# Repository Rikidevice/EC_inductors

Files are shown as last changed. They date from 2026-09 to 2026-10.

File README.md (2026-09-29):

# PWR_MOD — контроллер индуктивного измерения проводимости солей с регулировкой pH
# PWR_MOD — Inductive Salt Conductivity Meter with pH Control

[Русский](#русская-версия) · [English](#english-version)

---

## Русская версия

Плата управления для системы индуктивного (бесконтактного) измерения
проводимости солей трендового типа с автоматической коррекцией pH.
Поддерживает два варианта управляющего модуля: **ESP32 / ESP32-S3-1.47**
и **STM32F407VET6**. Связь по **Modbus (RTU/ASCII)**.

### Возможности

- **Индуктивный метод измерения проводимости солей**
  - Приём сигнала с катушки детекции (Rx) через **полноценный АЦП**
    с **гальванической развязкой**.
  - Отдельный канал измерения **pH** (также через развязанный АЦП).
- **Температурный контроль**
  - **DS18B20** — температура жидкости (1-Wire).
  - **DHT22 (AM2302)** — температура и влажность воздуха в помещении.
- **Управляющие модули (на выбор / распайка под оба):**
  - `ESP32` (WROOM-32 и совместимые);
  - `ESP32-S3-1.47` (дисплейный модуль);
  - `STM32F407VET6`.
- **Два шаговых двигателя** для дозирования:
  - `pH Up` — драйвер A4988;
  - `pH Down` — драйвер A4988.
- **Modbus**
- **Питание и защита** — 12В от 1А

### Аппаратная часть

| Узел | Реализация | Примечание |
|---|---|---|
| MCU | ESP32 / ESP32-S3-1.47 / STM32F407VET6 | выбор при сборке |
| АЦП (Rx катушки) | MCP3551 | гальваническая развязка |
| АЦП (pH) | ADS1232 | гальваническая развязка |
| Датчик температуры жидкости | DS18B20 | 1-Wire |
| Датчик температуры/влажности воздуха | DHT22 (AM2302) | 1-Wire-подобный |
| Драйвер ШД №1 (pH Up) | A4988 | полноценная обвязка |
| Драйвер ШД №2 (pH Down) | A4988 | полноценная обвязка |
| Интерфейс связи | Modbus RTU / ASCII | RS-485 - SN65HVD72DR |

**Плата:** 4 слоя, 111,1-91,3 мм.

### Прошивка и протокол

- **Modbus:** [RTU / ASCII], адрес по умолчанию — `[1]`,
  скорость — `[9600 8N1 / 19200 8N1]`.
- **Карта регистров:** [ссылка на docs/modbus_registers.md или таблицу ниже].

#### Карта регистров (черновик)

| Адрес | R/W | Описание | Ед. |
|---|---|---|---|
| 0x0000 | R | Проводимость солей | мкСм/см |
| 0x0001 | R | pH | pH |
| 0x0002 | R | Температура жидкости (DS18B20) | °C |
| 0x0003 | R | Температура воздуха (DHT22) | °C |
| 0x0004 | R | Влажность воздуха (DHT22) | % |
| 0x0010 | W | Уставка pH | pH |
| 0x0011 | W | Команда насоса pH Up | — |
| 0x0012 | W | Команда насоса pH Down | — |
| 0x00FF | R/W | Служебный / версия ПО | — |

### Сборка и запуск

1. Подать питание 12В (есть защита от полярности).
2. Проверить индикацию [PWR, RUN].
3. Подключить сборку из катушек Tx [L2], Rx [L3].
4. Подключить pH-электрод к разъёму [J5].
5. Подключить DS18B20 к разъёму [18b20].
6. Подключить DHT22 к разъёму [DHT22].
7. Подключить RS-485 (A/B/GND) [J11]  к верхнему уровню.
8. Подать команду по Modbus и убедиться в отклике.

### Безопасность

- Измерительная и цифровая части разделены по земле и питанию.
- Шаговые двигатели питаются от входного напряжения 12В

### Лицензия

Проект распространяется под лицензией **MIT**. Полный текст — в файле [`LICENSE`](LICENSE).

### Автор

[Talgat / RikiDevice] — [rikimtfree@gmail.com]

---

## English version

Control board for an inductive (non-contact) salt conductivity measurement
system of trending type with automatic pH correction.
Supports two control module options: **ESP32 / ESP32-S3-1.47**
and **STM32F407VET6**. Communication over **Modbus (RTU/ASCII)**.

### Features

- **Inductive salt conductivity measurement**
  - Detection coil (Rx) signal acquisition via a **full-featured ADC**
    with **galvanic isolation**.
  - Dedicated **pH** measurement channel (also via isolated ADC).
- **Temperature monitoring**
  - **DS18B20** — liquid temperature (1-Wire).
  - **DHT22 (AM2302)** — ambient air temperature and humidity.
- **Control modules (selectable / footprint for both):**
  - `ESP32` (WROOM-32 and compatible);
  - `ESP32-S3-1.47` (display module);
  - `STM32F407VET6`.
- **Two stepper motors** for dosing:
  - `pH Up` — A4988 driver;
  - `pH Down` — A4988 driver.
- **Modbus** — communication with upper layer (PLC / SCADA / PC).
- **Power and protection** — [specify: input voltage, regulators,
  overcurrent protection, TVS, etc.].

### Hardware

| Block | Implementation | Notes |
|---|---|---|
| MCU | ESP32 / ESP32-S3-1.47 / STM32F407VET6 | selected at build time |
| ADC (Rx coil) | [part] | galvanically isolated |
| ADC (pH) | [part] | galvanically isolated |
| Liquid temperature sensor | DS18B20 | 1-Wire, [parasitic/external power] |
| Ambient temp/humidity sensor | DHT22 (AM2302) | 1-Wire-like, [4.7–10 kΩ pull-up] |
| Stepper driver #1 (pH Up) | A4988 | full support circuitry |
| Stepper driver #2 (pH Down) | A4988 | full support circuitry |
| Communication | Modbus RTU / ASCII | RS-485 [transceiver] |
| Power | [voltage] | [regulators / protections] |

**PCB:** 4 layers, [size, mm], [thickness, mm], [accuracy class].

### Repository layout
PWR_MOD/
├─ PWR_MOD.kicad_pro # KiCad project
├─ PWR_MOD.kicad_sch # schematic
├─ PWR_MOD.kicad_pcb # PCB layout
├─ gerbers/ # Gerber + drill files
├─ docs/ # datasheets, PDFs, notes
│ ├─ schematic.pdf
│ ├─ pcb_top.pdf
│ └─ pcb_bottom.pdf
├─ firmware/ # firmware sources (if any)
├─ .gitignore
└─ README.md
text

### Fabrication

1. Open the project in **KiCad [version]**.
2. Run ERC (schematic) and DRC (PCB) — report saved to `docs/`.
3. Generate Gerber + Excellon (drill) into `gerbers/`.
4. Send `gerbers/*.zip` to the PCB house.
   - Layers: 4 (Top, Inner1, Inner2, Bottom).
   - [Optional] controlled impedance if required for the detection coil.

### Firmware and protocol

- **Modbus:** [RTU / ASCII], default address — `[1]`,
  default baud — `[9600 8N1 / 19200 8N1]`.
- **Register map:** [link to docs/modbus_registers.md or table below].

#### Register map (draft)

| Address | R/W | Description | Unit |
|---|---|---|---|
| 0x0000 | R | Salt conductivity | µS/cm |
| 0x0001 | R | pH | pH |
| 0x0002 | R | Liquid temperature (DS18B20) | °C |
| 0x0003 | R | Ambient temperature (DHT22) | °C |
| 0x0004 | R | Ambient humidity (DHT22) | % |
| 0x0010 | W | pH setpoint | pH |
| 0x0011 | W | pH Up pump command | — |
| 0x0012 | W | pH Down pump command | — |
| 0x00FF | R/W | Service / firmware version | — |

### Assembly and startup

1. Apply power [voltage, polarity].
2. Check indicators [PWR, RUN, ERR].
3. Connect the Rx coil to connector [J?].
4. Connect the pH electrode to connector [J?].
5. Connect DS18B20 to connector [J?].
6. Connect DHT22 to connector [J?].
7. Connect RS-485 (A/B/GND) to the upper layer.
8. Send a Modbus command and verify the response.

### Safety

- Galvanic isolation of the ADC is mandatory: measurement and digital
  sections are separated by ground and power.
- Stepper motors are powered from a separate [voltage] rail and **must not**
  share ground with the isolated ADC.
- When handling pH reagents (Up/Down), observe [safety precautions].

### License

The project is distributed under the MIT license. The full text is in the [`LICENSE`](LICENSE).

### Author

[Talgat / RikiDevice] — [rikimtfree@gmail.com]

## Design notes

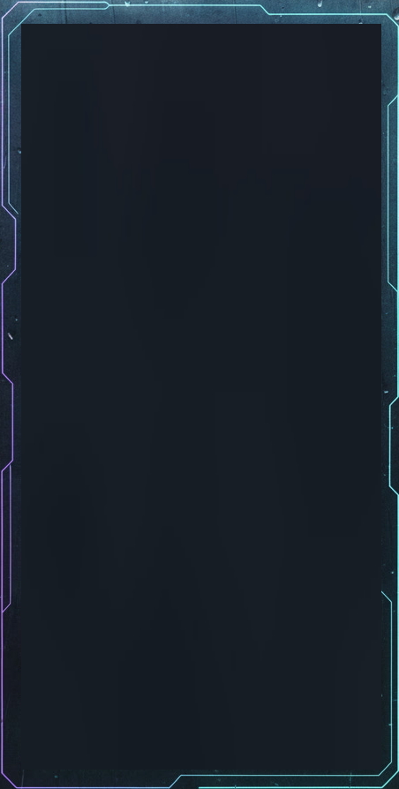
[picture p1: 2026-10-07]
UI/interface.jpg

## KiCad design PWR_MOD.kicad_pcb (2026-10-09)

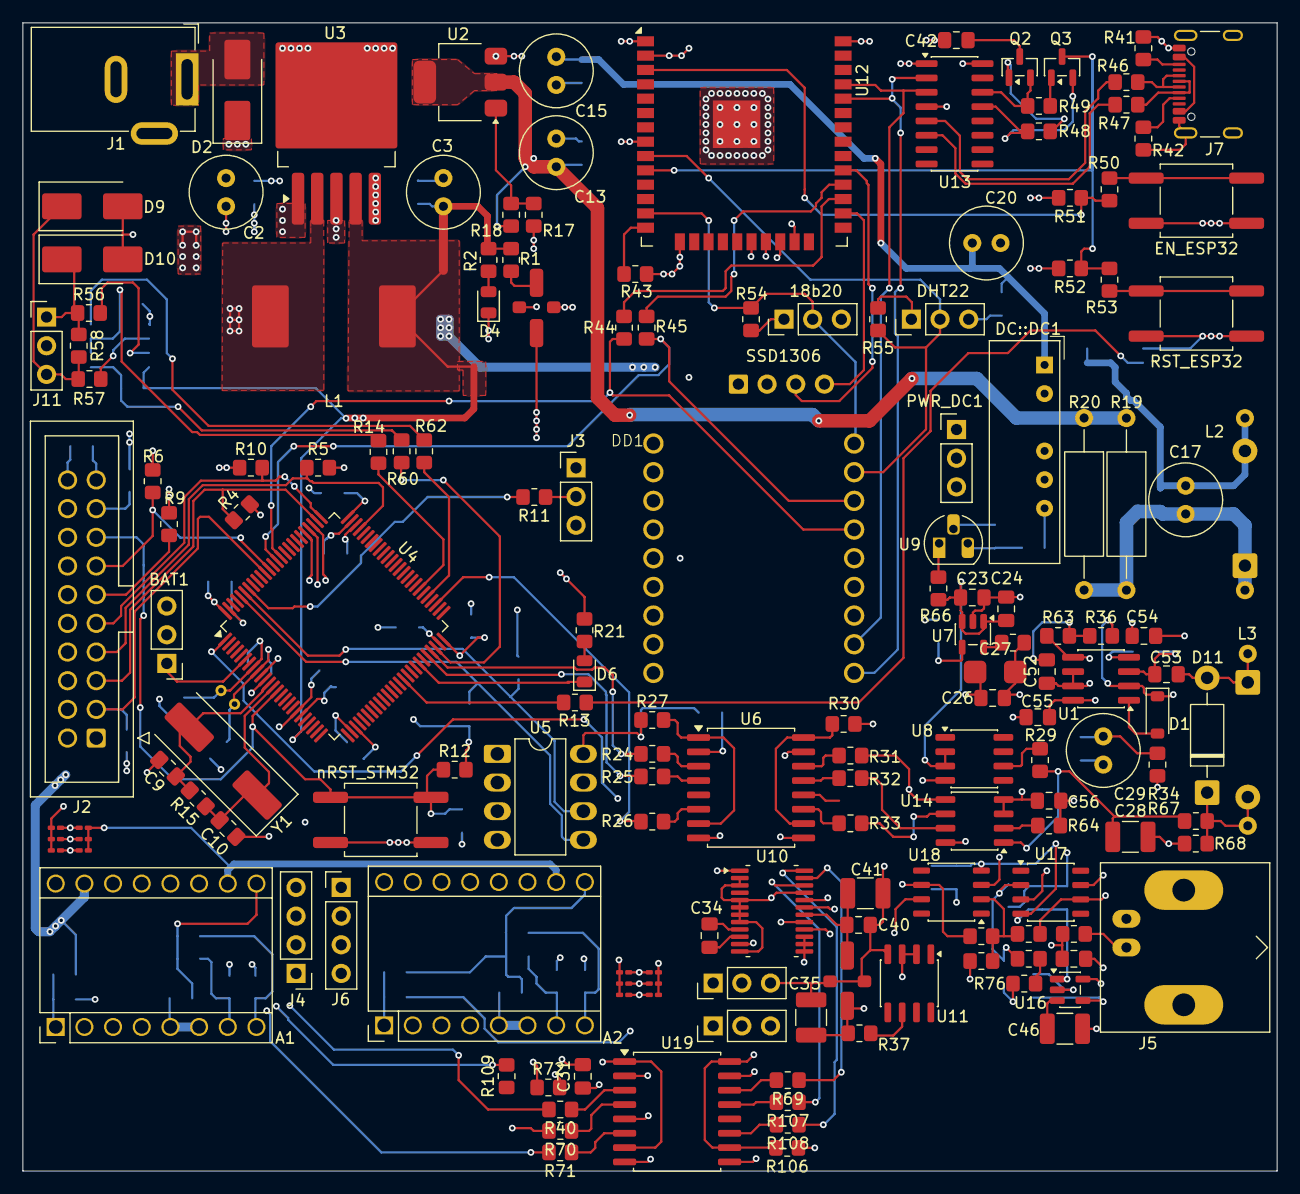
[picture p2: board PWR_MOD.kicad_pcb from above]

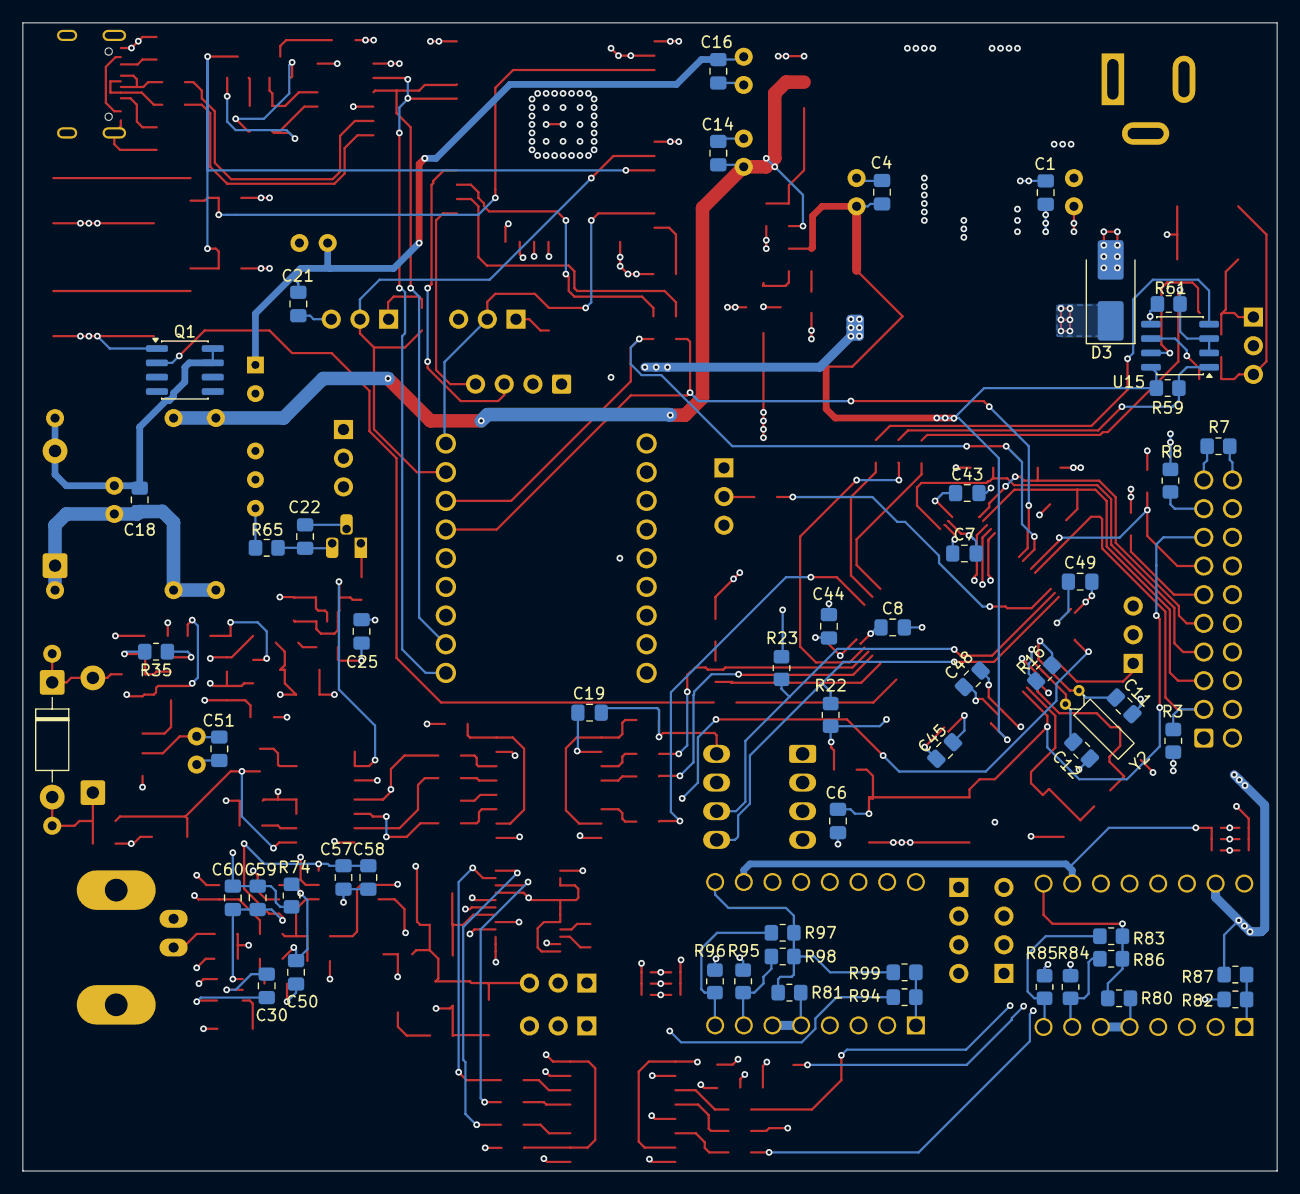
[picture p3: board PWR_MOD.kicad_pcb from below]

Board: 4 copper layers, 111.1 x 101.7 mm, 221 parts (57 on the bottom side), 164 nets.

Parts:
18b20: Conn_01x03; PinHeader_1x03_P2.54mm_Vertical
A1, A2: Pololu_Breakout_A4988; Pololu_Breakout-16_15.2x20.3mm
BAT1: Conn_01x03; PinHeader_1x03_P2.54mm_Vertical
C1, C4, C14, C16, C18, C21, C22, C23, C25: C_Small; C_0805_2012Metric_Pad1.18x1.45mm_HandSolder
C2, C3, C13, C15, C17, C20: C_Polarized_Small; C_Radial_D6.3mm_H7.0mm_P2.50mm
C5, C39: C_Feedthrough; L_0805_2012Metric_Pad1.05x1.20mm_HandSolder
C6, C7, C8, C19, C31, C43, C44, C45, C48, C49: 0.1 uF; C_0805_2012Metric_Pad1.18x1.45mm_HandSolder
C9, C10, C11, C12: 10 pF; C_0805_2012Metric_Pad1.18x1.45mm_HandSolder
C24: 0,1 uF; C_0805_2012Metric_Pad1.18x1.45mm_HandSolder
C26, C27, C40, C51: 6800; C_0805_2012Metric_Pad1.18x1.45mm_HandSolder
C28, C35, C46: 10 uF; C_1210_3225Metric_Pad1.33x2.70mm_HandSolder
C29: 220 uF; C_Radial_D6.3mm_H7.0mm_P2.50mm
C30: 100n; C_0805_2012Metric_Pad1.18x1.45mm_HandSolder
C34, C42: 1 uF; C_0805_2012Metric_Pad1.18x1.45mm_HandSolder
C41: 47 uF; C_1210_3225Metric_Pad1.33x2.70mm_HandSolder
C47: 2.2n; C_0805_2012Metric_Pad1.18x1.45mm_HandSolder
C50, C57, C58, C59, C60: 1u; C_0805_2012Metric_Pad1.18x1.45mm_HandSolder
C52: 21 old 150; C_0805_2012Metric_Pad1.18x1.45mm_HandSolder
C53, C55: 1500; C_0805_2012Metric_Pad1.18x1.45mm_HandSolder
C54: 51 old 330; C_0805_2012Metric_Pad1.18x1.45mm_HandSolder
C56: ???; C_0805_2012Metric_Pad1.18x1.45mm_HandSolder
D1: MBR0540; D_SOD-123
D2, D3, D9, D10: SS24; D_SMB_Handsoldering
D4, D6: LED; LED_0805_2012Metric
D5, D8, D11: 1N4007; D_DO-41_SOD81_P10.16mm_Horizontal
DC::DC1: Converter_DCDC_Murata_NMAxxxxSC_THT
DD1: Без имени
DHT22: Conn_01x03; PinHeader_1x03_P2.54mm_Vertical
EN_ESP32: boot; SW_Push_1P1T_NO_CK_KSC6xxG
GAIN1, GAIN2: Conn_01x03; PinHeader_1x03_P2.54mm_Vertical
J1: Barrel_Jack; BarrelJack_GCT_DCJ200-10-A_Horizontal
J2: Conn_ARM_JTAG_SWD_20; IDC-Header_2x10_P2.54mm_Vertical
J3, J11: Conn_01x03; PinHeader_1x03_P2.54mm_Vertical
J4, J6: Conn_01x04_Pin; PinHeader_1x04_P2.54mm_Vertical
J5: Conn_Coaxial; BNC_Amphenol_B6252HB-NPP3G-50_Horizontal
J7: USB_C_Receptacle_USB2.0_16P; USB_C_Receptacle_GCT_USB4105-xx-A_16P_TopMnt_Horizontal
L1: L; L_Changjiang_FXL1340
L2: Tx; R_Axial_DIN0309_L9.0mm_D3.2mm_P15.24mm_Horizontal
L3: Rx; R_Axial_DIN0309_L9.0mm_D3.2mm_P15.24mm_Horizontal
PWR_DC1: Conn_01x03; PinHeader_1x03_P2.54mm_Vertical
Q1: IRF7341PBF; SOIC-8_3.9x4.9mm_P1.27mm
Q2, Q3: SS8050; SOT-23
R1, R28, R29, R37, R65, R66: 0; R_0805_2012Metric_Pad1.20x1.40mm_HandSolder
R2, R24, R25, R26, R31, R32, R33, R40, R69, R70, R71, R74, R107, R108, R109: 1k; R_0805_2012Metric_Pad1.20x1.40mm_HandSolder
R3, R4, R5, R6, R7, R8, R9, R10, R35, R43, R51, R52, R59, R61, R67, R68: 10k; R_0805_2012Metric_Pad1.20x1.40mm_HandSolder
R11, R12, R17, R21: 3.3k; R_0805_2012Metric_Pad1.20x1.40mm_HandSolder
R13, R14, R27, R30, R50, R53, R72, R106: 100; R_0805_2012Metric_Pad1.20x1.40mm_HandSolder
R15, R16: 1M; R_0805_2012Metric_Pad1.20x1.40mm_HandSolder
R18: 560; R_0805_2012Metric_Pad1.20x1.40mm_HandSolder
R19, R20: R; R_Axial_DIN0309_L9.0mm_D3.2mm_P15.24mm_Horizontal
R22, R23, R80, R81, R83, R86, R87, R97, R98, R99: 4.7k; R_0805_2012Metric_Pad1.20x1.40mm_HandSolder
R34: 100k; R_0805_2012Metric_Pad1.20x1.40mm_HandSolder
R36, R63: 3.6k; R_0805_2012Metric_Pad1.20x1.40mm_HandSolder
R41, R42: 5.1k; R_0805_2012Metric_Pad1.20x1.40mm_HandSolder
R44, R45, R46, R47, R56, R57, R60, R62, R64: 10; R_0805_2012Metric_Pad1.20x1.40mm_HandSolder
R48, R49: 12k; R_0805_2012Metric_Pad1.20x1.40mm_HandSolder
R54, R55: 4,7k; R_0805_2012Metric_Pad1.20x1.40mm_HandSolder
R58: 120; R_0805_2012Metric_Pad1.20x1.40mm_HandSolder
R73: 4.7M; R_0805_2012Metric_Pad1.20x1.40mm_HandSolder
R75: 1-5k*; R_0805_2012Metric_Pad1.20x1.40mm_HandSolder
R76: 2.2k; R_0805_2012Metric_Pad1.20x1.40mm_HandSolder
R77, R78: 30k; R_0805_2012Metric_Pad1.20x1.40mm_HandSolder
R79: 75k; R_0805_2012Metric_Pad1.20x1.40mm_HandSolder
R82, R84, R85, R94, R95, R96: 220; R_0805_2012Metric_Pad1.20x1.40mm_HandSolder
R88, R89, R90, R91, R92, R93, R100, R101, R102, R103, R104, R105: 4.7k; R_0201_0603Metric_Pad0.64x0.40mm_HandSolder
RST_ESP32: SW_Push; SW_Push_1P1T_NO_CK_KSC6xxG
SSD1306: ER_OLEDM0.91_1x-I2C
U1: AD8606ARZ; SOIC-8_3.9x4.9mm_P1.27mm
U2: LM317_SOT-223; SOT-223-3_TabPin2
U3: LM2576S-ADJ; TO-263-5_TabPin3
U4: STM32F407VETx; LQFP-100_14x14mm_P0.5mm
U5: 24LC256; DIP-8_W7.62mm_LongPads
U6, U19: ADuM1401xRW; SOIC-16W_7.5x10.3mm_P1.27mm
U7: LP2985-3.3; SOT-23-5
U8, U11: REF195; SO-8_3.9x4.9mm_P1.27mm
U9: L7809; TO-92L_HandSolder
U10: ADS1232IPW; HTSSOP-24-1EP_4.4x7.8mm_P0.65mm_EP3.4x7.8mm_Mask2.4x4.68mm
U12: ESP32-WROOM-32
U13: CH340C; SOIC-16_3.9x9.9mm_P1.27mm
U14: MCP3551-EMS; SO-8_3.9x4.9mm_P1.27mm
U15: SO-8_3.9x4.9mm_P1.27mm
U16: TPS60400DBV; SOT-23-5
U17: CA3140; JEITA_SOIC-8_3.9x4.9mm_P1.27mm
U18: TL081; JEITA_SOIC-8_3.9x4.9mm_P1.27mm
Y1: 8 MHz; Crystal_SMD_HC49-SD
Y2: 32k; Crystal_DS15_D1.5mm_L5.0mm_Horizontal
nRST_STM32: SW_Push; SW_Push_1P1T_NO_CK_KSC6xxG

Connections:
+3.3 VDD: C5.3, C19.1, C31.1, C43.2, C44.2, C45.2, C48.2, C49.2, J2.1 (VTREF), J2.2 (VCC/NC), J3.1, R3.2, R4.2, R5.2, R6.2, R12.2, R21.2, R22.1, R23.1, R27.1, R72.1, U4.11 (VDD), U4.19 (VDD), U4.28 (VDD), U4.50 (VDD), U4.75 (VDD), U4.100 (VDD), U5.8 (VCC)
+3.3 VDDA: 18b20.1, A1.10 (VDD), A2.10 (VDD), C3.1, C4.1, DD1.3V3, DHT22.1, L1.2, R1.1, R2.1, R51.2, R52.2, R54.2, R55.2, R59.1, R91.1, R92.1, R93.1, R100.1, R101.1, R102.1, SSD1306.2 (VCC), U3.4 (FB), U4.22 (VDDA), U12.2 (VDD), U13.4 (V3), U13.16 (VCC), U15.8 (VCC)
+3.3V1: C26.1, C27.1, C55.2, GAIN1.1, GAIN2.1, R28.2, R30.1, R106.1, U1.8 (V+), U10.1 (DVDD), U14.8 (Vdd)
+9: C13.1, C14.1, R18.1, R19.1, R20.1, U2.2 (VO)
+9V1: C23.1, C24.1, PWR_DC1.2, R66.1, U7.1 (VIN), U7.3 (ON/~OFF), U8.2 (Vin), U8.3 (~Sleep), U11.2 (Vin), U11.3 (~Sleep)
+OUT DC: C22.1, PWR_DC1.3, R65.1, U9.3 (IN)
+V: A1.16 (VMOT), A2.16 (VMOT), C1.1, C2.1, C15.1, C16.1, C20.1, C21.1, D2.1 (K), DC::DC1.1 (+Vin), U2.3 (VI), U3.1 (VIN)
+VIN: D2.2 (A), J1.1
+Vin_ADC: R64.1, U14.2 (Vin+)
+Vref: C28.1, R29.2, R67.1, U14.1 (Vref)
+Vref_1232: C30.1, C35.1, C39.1, R37.2, U10.16 (REFP), U16.2 (IN), U17.7 (V+), U18.7 (V+)
-Vin_ADC: C22.2, C23.2, C24.2, C25.2, C26.2, C27.2, C28.2, C29.2, C30.2, C35.2, C39.2, C40.2, C41.2, C47.1, C51.2, C54.1, C55.1, C56.1, C57.1, C58.1, C59.1, C60.1, DC::DC1.4 (-Vout), GAIN1.3, GAIN2.3, J5.2 (Ext), PWR_DC1.1, R34.1, R35.1, R68.1, R74.1, U1.4 (V-), U6.9 (GND2), U6.15 (GND2), U7.2 (GND), U8.4 (GND), U9.2 (GND), U10.2 (DGND), U10.3 (CLKIN/XTAL1), U10.5 (DGND), U10.6 (DGND), U10.7 (TEMP), U10.8 (A0), U10.12 (AINN1), U10.13 (AINN2), U10.14 (AINP2), U10.15 (REFN), U10.17 (AGND), U10.21 (SPEED), U11.4 (GND), U14.3 (Vin-), U14.4 (Vss), U16.4 (GND), U18.3 (+), U19.9 (GND2), U19.15 (GND2)
-Vref: C57.2, C58.2, C59.2, C60.2, R79.1, U16.1 (OUT), U17.4 (V-), U18.4 (V-)
AinP1: R78.2, U10.11 (AINP1), U18.6
BOOT0: R11.2, U4.94 (BOOT0)
CS: R25.2, U4.46 (PE15)
CS_1: R32.1, U14.7 (~CS)
CS_1232: R107.1, U10.22 (~PWDN)
CS_ADS1232: R70.2, U4.1 (PE2)
D+: J7.A6 (D+), J7.B6 (D+), R46.1
D-: J7.A7 (D-), J7.B7 (D-), R47.1
DIR: DD1.2, R85.1, R96.1, U12.21 (SDO/SD0)
DOUT_ADS1232: R108.1, U10.24 (~DRDY/DOUT)
DTR: Q3.2 (E), R48.1, U13.13 (~DTR)
EN: R50.2, R51.1, U12.3 (EN)
G0: GAIN1.2, U10.19 (GAIN0)
G1: GAIN2.2, U10.20 (GAIN1)
GND_0: 18b20.3, A1.9 (GND), A1.15 (GND), A2.9 (GND), A2.15 (GND), BAT1.2, BAT1.3, C1.2, C2.2, C3.2, C4.2, C5.2, C6.2, C7.2, C8.2, C9.2, C10.2, C11.2, C12.2, C13.2, C14.2, C15.2, C16.2, C19.2, C20.2, C21.2, C31.2, C42.2, C43.1, C44.1, C45.1, C48.1, C49.1, D3.2 (A), D4.1 (K), D9.2 (A), D10.2 (A), DC::DC1.2 (-Vin), DD1.GND, DHT22.3, EN_ESP32.2, J1.2, J2.4 (GND), J2.6 (GND), J2.8 (GND), J2.10 (GND), J2.12 (GND), J2.14 (GND), J2.16 (GND), J2.18 (GND), J2.20 (GND), J3.3, J7.A1 (GND), J7.A12 (GND), J7.B1 (GND), J7.B12 (GND), J7.SH (SHIELD), J11.2, Q1.1 (S1), R7.1, R8.1, R9.1, R10.1, R17.1, R41.2, R42.2, R43.2, R61.2, R80.1, R81.1, R83.1, R86.1, R87.1, R88.1, R89.1, R90.1, R97.1, R98.1, R99.1, R103.1, R104.1, R105.1, RST_ESP32.2, SSD1306.1 (GND), U3.3 (GND), U3.5 (~ON/OFF), U4.10 (VSS), U4.20 (VSSA), U4.27 (VSS), U4.74 (VSS), U4.99 (VSS), U5.1 (A0), U5.2 (A1), U5.3 (A2), U5.4 (GND), U5.7 (WP), U6.2 (GND1), U6.5 (VIC), U6.8 (GND1), U12.1 (GND), U12.8 (IO32), U12.15 (GND), U12.38 (GND), U12.39 (GND), U13.1 (GND), U15.5 (GND), U19.2 (GND1), U19.5 (VIC), U19.8 (GND1), nRST_STM32.2
IIC_SCL: SSD1306.3 (SCL), U12.29 (IO5)
IIC_SDA: SSD1306.4 (SDA), U12.26 (IO4)
IO0: Q3.3 (C), R52.1, R53.2, U12.10 (IO25)
JTCK: J2.9 (TCK/SWCLK), R10.2, U4.76 (SYS_JTCK-SWCLK)
JTDI: J2.5 (TDI), R4.1, U4.77 (SYS_JTDI)
JTDO: J2.13 (TDO/SWO), R6.1, U4.89 (SYS_JTDO-SWO)
JTMS: J2.7 (TMS/SWDIO), R5.1, U4.72 (SYS_JTMS-SWDIO)
LC_Tx: Q1.2 (G1), R13.2
LED_TEST: D6.1 (K), U4.44 (PE13)
M1: DD1.3, R82.1, U12.22 (SDI/SD1)
M2: DD1.4, R94.1, U12.23 (IO15)
MISO_AD1232: R71.2, U4.79 (PC11)
MOSI_AD1232: R109.2, U4.80 (PC12)
unnamed: A1.12 (1A), J4.3
unnamed: A1.11 (1B), J4.4
unnamed: A1.13 (2A), J4.2
unnamed: A1.14 (2B), J4.1
unnamed: A1.8 (DIR), R83.2, R85.2
unnamed: A1.2 (MS1), R90.2, R91.2
unnamed: A1.3 (MS2), R89.2, R92.2
unnamed: A1.4 (MS3), R88.2, R93.2
unnamed: A1.7 (STEP), R84.2, R86.2
unnamed: A1.1 (~ENABLE), R82.2, R87.2
unnamed: A1.5 (~RESET), A1.6 (~SLEEP), R80.2
unnamed: A2.12 (1A), J6.3
unnamed: A2.11 (1B), J6.4
unnamed: A2.13 (2A), J6.2
unnamed: A2.14 (2B), J6.1
unnamed: A2.8 (DIR), R96.2, R97.2
unnamed: A2.2 (MS1), R100.2, R103.2
unnamed: A2.3 (MS2), R101.2, R104.2
unnamed: A2.4 (MS3), R102.2, R105.2
unnamed: A2.7 (STEP), R95.2, R98.2
unnamed: A2.1 (~ENABLE), R94.2, R99.2
unnamed: A2.5 (~RESET), A2.6 (~SLEEP), R81.2
unnamed: C5.1, R1.2
unnamed: C34.1, U10.9 (CAP)
unnamed: C34.2, U10.10 (CAP)
unnamed: C50.2, R76.2, R77.1, U17.6
unnamed: C52.1, R36.1, R63.2
unnamed: D1.2 (A), U1.1
unnamed: C29.1, C51.1, D1.1 (K), R34.2, R36.2, U1.2 (-)
unnamed: D3.1 (K), L1.1, U3.2 (OUT)
unnamed: D4.2 (A), R2.2
unnamed: C17.2, C18.2, D5.2 (A), L2.2, Q1.7 (D1), Q1.8 (D1)
unnamed: C17.1, C18.1, D5.1 (K), L2.1, R19.2, R20.2
unnamed: D6.2 (A), R21.1
unnamed: D9.1 (K), J11.3, R57.1, R58.2
unnamed: D10.1 (K), J11.1, R56.1, R58.1
unnamed: C53.1, D8.1 (K), D11.2 (A), L3.2
unnamed: D8.2 (A), D11.1 (K), L3.1, R67.2, R68.2
unnamed: DC::DC1.6 (+Vout), R65.2
unnamed: EN_ESP32.1, R50.1
unnamed: J2.19 (DBGACK/NC), R7.2
unnamed: J2.17 (DBGRQ/NC), R8.2
unnamed: J2.11 (RTCK), R9.2
unnamed: J3.2, R11.1
unnamed: J5.1 (In), R73.1
unnamed: J7.A5 (CC1), R42.1
unnamed: J7.B5 (CC2), R41.1
unnamed: J7.A4 (VBUS), J7.A9 (VBUS), J7.B4 (VBUS), J7.B9 (VBUS)
unnamed: Q2.1 (B), R48.2
unnamed: C42.1, Q2.3 (C)
unnamed: Q3.1 (B), R49.2
unnamed: R53.1, RST_ESP32.1
unnamed: R75.2, R76.1
unnamed: C53.2, R35.2, U1.3 (+)
unnamed: C54.2, R63.1, U1.5 (+)
unnamed: C52.2, C56.2, R64.2, U1.6 (-), U1.7
unnamed: R17.2, R18.2, U2.1 (ADJ)
unnamed: R14.1, U4.57 (PD10)
unnamed: R13.1, U4.40 (PE9)
unnamed: R27.2, U6.1 (VDD1), U6.7 (VE1)
unnamed: R30.2, U6.10 (VE2), U6.16 (VDD2)
unnamed: R24.1, U6.3 (VIA)
unnamed: R25.1, U6.4 (VIB)
unnamed: R33.2, U6.11 (VID)
unnamed: R31.2, U6.14 (VOA)
unnamed: R32.2, U6.13 (VOB)
unnamed: R26.1, U6.6 (VOD)
unnamed: C25.1, U7.4 (BP)
unnamed: R28.1, U7.5 (VOUT)
unnamed: R29.1, U8.6 (Vout)
unnamed: R66.2, U9.1 (OUT)
unnamed: C39.3, C40.1, C41.1, U10.18 (AVDD)
unnamed: R37.1, U11.6 (Vout)
unnamed: R43.1, U12.14 (IO12)
unnamed: R44.1, U12.27 (IO16)
unnamed: R45.1, U12.28 (IO17)
unnamed: R46.2, U13.5 (UD+)
unnamed: R47.2, U13.6 (UD-)
unnamed: R57.2, U15.6 (A)
unnamed: R56.2, U15.7 (B)
unnamed: R62.1, U15.4 (DI)
unnamed: R59.2, R60.1, U15.1 (RO)
unnamed: C46.1, U16.5 (C_{FLY+})
unnamed: C46.2, U16.3 (C_{FLY-})
unnamed: C47.2, R73.2, U17.3 (+)
unnamed: C50.1, R74.2, R75.1, U17.2 (-)
unnamed: R77.2, R78.1, R79.2, U18.2 (-)
unnamed: R72.2, U19.1 (VDD1), U19.7 (VE1)
unnamed: R106.2, U19.10 (VE2), U19.16 (VDD2)
unnamed: R40.1, U19.3 (VIA)
unnamed: R70.1, U19.4 (VIB)
unnamed: R108.2, U19.11 (VID)
unnamed: R69.2, U19.14 (VOA)
unnamed: R107.2, U19.13 (VOB)
unnamed: R71.1, U19.6 (VOD)
OSC32_IN: C11.1, R16.2, U4.8 (RCC_OSC32_IN), Y2.2
OSC32_OUT: C12.1, R16.1, U4.9 (RCC_OSC32_OUT), Y2.1
OSC_IN: C9.1, R15.2, U4.12 (RCC_OSC_IN), Y1.2
OSC_OUT: C10.1, R15.1, U4.13 (RCC_OSC_OUT), Y1.1
OneWire 18b20: 18b20.2, DD1.7, R54.1, U12.13 (IO14)
OneWire DHT11: DD1.8, DHT22.2, R55.1, U12.9 (IO33)
RTS: Q2.2 (E), R49.1, U13.14 (~RTS)
SCK: R24.2, U4.47 (PB10)
SCK_1: R31.1, U14.5 (SCK)
SCK_STM32_AD1232: R40.2, U4.78 (PC10)
SCLK_ADS1232: R69.1, U10.23 (SCLK)
SCL_I2C1: R23.2, U4.95 (PB8), U5.6 (SCL)
SDA_I2C1: R22.2, U4.96 (PB9), U5.5 (SDA)
SDO: R26.2, U4.53 (PB14)
SDO_1: R33.1, U14.6 (SDO/~RDY)
STP: DD1.0, R84.1, R95.1, U12.20 (SCK/CLK)
U0R: DD1.TXD, U12.34 (RXD0/IO3), U13.2 (TXD)
U0T: DD1.RXD, U12.35 (TXD0/IO1), U13.3 (RXD)
U2RxD: DD1.10, R44.2, U4.86 (PD5)
U2TxD: DD1.9, R45.2, U4.87 (PD6)
U3CK: R14.2, R61.1, U15.2 (RE), U15.3 (DE)
U3RxD: R60.2, U4.48 (PB11)
U3TxD: R62.2, U4.55 (PD8)
VBAT: BAT1.1, U4.6 (VBAT)
VCAP2: C7.1, U4.73 (VCAP_2)
VCAP_1: C8.1, U4.49 (VCAP_1)
nRST: C6.1, J2.15 (~SRST), R12.1, U4.14 (NRST), nRST_STM32.1
nTRST: J2.3 (~TRST), R3.1, U4.90 (SYS_JTRST)

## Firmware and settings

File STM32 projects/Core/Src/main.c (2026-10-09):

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
/* Includes ------------------------------------------------------------------*/
#include "main.h"

/* USER CODE BEGIN Includes */
#include <stdio.h>
#include <string.h>
extern UART_HandleTypeDef huart2;

#define MCP3551_CS_LOW()   HAL_GPIO_WritePin(GPIOE, GPIO_PIN_15, GPIO_PIN_RESET)
#define MCP3551_CS_HIGH()  HAL_GPIO_WritePin(GPIOE, GPIO_PIN_15, GPIO_PIN_SET)

#define ADS1232_CS_LOW()   HAL_GPIO_WritePin(GPIOE, GPIO_PIN_2, GPIO_PIN_RESET)
#define ADS1232_CS_HIGH()  HAL_GPIO_WritePin(GPIOE, GPIO_PIN_2, GPIO_PIN_SET)
/* USER CODE END Includes */

ADC_HandleTypeDef hadc1;

I2C_HandleTypeDef hi2c1;

SPI_HandleTypeDef hspi2;

TIM_HandleTypeDef htim1;

UART_HandleTypeDef huart2;
USART_HandleTypeDef husart3;

void SystemClock_Config(void);
static void MX_GPIO_Init(void);
static void MX_ADC1_Init(void);
static void MX_I2C1_Init(void);
static void MX_TIM1_Init(void);
static void MX_USART2_UART_Init(void);
static void MX_USART3_Init(void);
static void MX_SPI2_Init(void);
/* USER CODE BEGIN PFP */
uint8_t MCP3551_ReadData(SPI_HandleTypeDef *hspi, uint32_t *raw_data)
{
    uint8_t tx_buffer[4] = {0xFF, 0xFF, 0xFF, 0xFF};
    uint8_t rx_buffer[4] = {0};
    uint32_t timeout = HAL_GetTick() + 200;
        while(HAL_GPIO_ReadPin(GPIOB, GPIO_PIN_14) == GPIO_PIN_SET)
    {
        if(HAL_GetTick() > timeout) 
        {
            return 1;
        }
    }
    MCP3551_CS_LOW();
    HAL_Delay(100);
    HAL_SPI_TransmitReceive(hspi, tx_buffer, rx_buffer, 4, HAL_MAX_DELAY);
    MCP3551_CS_HIGH();
    *raw_data = ((uint32_t)rx_buffer[0] << 24) |
                ((uint32_t)rx_buffer[1] << 16) |
                ((uint32_t)rx_buffer[2] << 8)  |
                (uint32_t)rx_buffer[3];
    
    return 0;
}
/* USER CODE END PFP */

/* USER CODE BEGIN 0 */
uint8_t n=0;
uint8_t d=200;
uint8_t i=7;


uint32_t raw_data = 0;
uint8_t status = 0;

// Глобальные переменные
uint8_t rx_byte;
uint8_t rx_buffer[10];      // 11 байт данных после 0x0F
uint8_t rx_state = 0;       // 0 = ждём 0x0F, 1 = собираем
uint8_t rx_count = 0;
uint32_t freq = 0;
uint32_t duty = 0;
uint8_t samples = 0;
uint8_t cmd = 0;  // на самом деле 10-й байт, индекс 9
uint32_t adc_value=0;

//send UART2 PROTOTYPE FUNCTION


//*****************************
  void UART2_SendByte(uint8_t data) {
    while(!(USART2->SR & USART_SR_TXE)); 
    USART2->DR = data;                    
}

int putchar(int ch) {
    if (ch == '\n') {
        UART2_SendByte('\r');
    }
    UART2_SendByte((uint8_t)ch);
    return ch;
}
//*****************************


//*****************************
void HAL_UART_RxCpltCallback(UART_HandleTypeDef *huart)
{
    if (huart->Instance == USART2)
    {
        if (rx_state == 0)
        {
            if (rx_byte == 0x0F)
            {
                rx_state = 1;
                rx_count = 0;
                HAL_GPIO_TogglePin(GPIOE, GPIO_PIN_13);
            }
            HAL_UART_Receive_IT(&huart2, &rx_byte, 1);
        }
        else if (rx_state == 1)
        {
            if (rx_count < 10)  // ожидаем 10 байт после 0x0F
            {
                rx_buffer[rx_count++] = rx_byte;
                HAL_UART_Receive_IT(&huart2, &rx_byte, 1);
            }
            
            if (rx_count == 10)  // собрали все 10 байт
            {
                // Парсим (little-endian)
                freq = (uint32_t)rx_buffer[0] |
                       ((uint32_t)rx_buffer[1] << 8) |
                       ((uint32_t)rx_buffer[2] << 16) |
                       ((uint32_t)rx_buffer[3] << 24);
                duty = (uint32_t)rx_buffer[4] |
                       ((uint32_t)rx_buffer[5] << 8) |
                       ((uint32_t)rx_buffer[6] << 16) |
                       ((uint32_t)rx_buffer[7] << 24);
                samples = rx_buffer[8];   // теперь samples = 10
                cmd = rx_buffer[9];
                
                // Применить настройки ШИМ
                // SetPWM(freq, duty);
                
                
                // Формируем ответ
                uint8_t response[6];
                response[0] = 0xF0;
                uint32_t result = adc_value;
                response[1] = result & 0xFF;
                response[2] = (result >> 8) & 0xFF;
                response[3] = (result >> 16) & 0xFF;
                response[4] = (result >> 24) & 0xFF;
                response[5] = 0x01;
                
                HAL_UART_Transmit(&huart2, response, 6, 100);
                
                rx_state = 0;
                HAL_UART_Receive_IT(&huart2, &rx_byte, 1);
            }
        }
    }
}

//*****************************
/* USER CODE END 0 */

/**
  * @brief  The application entry point.
  * @retval int
  */
int main(void)
{
  /* MCU Configuration--------------------------------------------------------*/

  /* Reset of all peripherals, Initializes the Flash interface and the Systick. */
  HAL_Init();

  /* Configure the system clock */
  SystemClock_Config();

  /* Initialize all configured peripherals */
  MX_GPIO_Init();
  MX_ADC1_Init();
  MX_I2C1_Init();
  MX_TIM1_Init();
  MX_USART2_UART_Init();
  MX_USART3_Init();
  MX_SPI2_Init();
  /* USER CODE BEGIN 2 */
  HAL_GPIO_WritePin(GPIOE, GPIO_PIN_13, GPIO_PIN_SET);
  HAL_TIM_PWM_Start(&htim1, TIM_CHANNEL_1);
  HAL_UART_Receive_IT(&huart2, &rx_byte, 1);//обязательный запуск для первого запуска
  ADS1232_CS_LOW();
  
  MCP3551_CS_LOW();
  HAL_Delay(100);
  uint8_t tx_buffer[4] = {0xFF, 0xFF, 0xFF, 0xFF};
  uint8_t rx_buffer[4] = {0};
  HAL_SPI_TransmitReceive(&hspi2, tx_buffer, rx_buffer, 4, HAL_MAX_DELAY);
  MCP3551_CS_HIGH();
  HAL_Delay(100);
  /* USER CODE END 2 */

  /* Infinite loop */
  /* USER CODE BEGIN WHILE */
  while (1)
  {
    /* USER CODE END WHILE */

    /* USER CODE BEGIN 3 */
    for (n=1;n<=samples;n++)
    {
    TIM1->ARR=freq;
    TIM1->CCR1=duty;
    status = MCP3551_ReadData(&hspi2, &raw_data);
    if (status == 0){
    adc_value = (raw_data >> 6) & 0x3FFFFF;}
    HAL_Delay(d);
    }
  }
  /* USER CODE END 3 */
}

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


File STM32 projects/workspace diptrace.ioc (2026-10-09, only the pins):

Mcu.UserName=STM32F407VETx
PA1.Signal=ADCx_IN1
PA13.Signal=SYS_JTMS-SWDIO
PA14.Signal=SYS_JTCK-SWCLK
PA15.Signal=SYS_JTDI
PA2.Signal=ADCx_IN2
PA3.Signal=ADCx_IN3
PA4.Signal=GPXTI4
PA5.Signal=ADCx_IN5
PB10.Signal=SPI2_SCK
PB11.Signal=USART3_RX
PB12.Signal=GPIO_Output
PB13.Signal=GPIO_Output
PB14.Signal=SPI2_MISO
PB15.Signal=SPI2_MOSI
PB3.Signal=SYS_JTDO-SWO
PB4.Signal=SYS_JTRST
PB8.Signal=I2C1_SCL
PB9.Signal=I2C1_SDA
PC10.Signal=SPI3_SCK
PC11.Signal=SPI3_MISO
PC12.Signal=SPI3_MOSI
PC14-OSC32_IN.Signal=RCC_OSC32_IN
PC15-OSC32_OUT.Signal=RCC_OSC32_OUT
PD10.Signal=USART3_CK
PD5.Signal=USART2_TX
PD6.Signal=USART2_RX
PD8.Signal=USART3_TX
PE11.Signal=S_TIM1_CH2
PE13.Signal=GPIO_Output
PE15.Signal=GPIO_Output
PE2.Signal=GPIO_Output
PE9.Signal=S_TIM1_CH1
PH0-OSC_IN.Signal=RCC_OSC_IN
PH1-OSC_OUT.Signal=RCC_OSC_OUT

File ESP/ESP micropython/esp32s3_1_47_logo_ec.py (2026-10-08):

import machine
import time
import st7789py as st7789
import os
import gc
# ==================== SD-КАРТА ====================
for pin_num in (14, 15, 16, 17, 18, 21):
    machine.Pin(pin_num, machine.Pin.IN, machine.Pin.PULL_UP)
time.sleep_ms(100)

try:
    sd = machine.SDCard(slot=1, width=4, sck=14, cmd=15, data=(16, 18, 17, 21))
    vfs = os.VfsFat(sd)
    try: 
        os.mount(vfs, "/sd")
    except Exception as e:
        pass
    print("SD Card OK")
except Exception as e:
    print(f"SD Error: {e}")
# ==================== ДИСПЛЕЙ ====================
rst_pin = machine.Pin(39, machine.Pin.OUT)
rst_pin.value(0); time.sleep_ms(50); rst_pin.value(1); time.sleep_ms(50)

backlight = machine.Pin(46, machine.Pin.OUT)
backlight.value(1)

spi = machine.SPI(1, baudrate=60000000, polarity=0, phase=0,
                  sck=machine.Pin(40), mosi=machine.Pin(45))

display = st7789.ST7789(spi, 240, 320, reset=None, 
                        cs=machine.Pin(42, machine.Pin.OUT), 
                        dc=machine.Pin(41, machine.Pin.OUT), rotation=1)

display.width = 320
display.height = 172
display.xstart = 0
display.ystart = 34
# ==================== ФУНКЦИЯ ВОСПРОИЗВЕДЕНИЯ RAW ВИДЕО ====================
# ==================== ИНИЦИАЛИЗАЦИЯ БУФЕРА КАДРА ====================

# Выносим создание буфера из функции на глобальный уровень.
# Перед созданием максимально жестко очищаем память от прошлых запусков.
gc.collect()
time.sleep_ms(50)
gc.threshold(gc.mem_free() // 4) # Заставляем GC работать агрессивнее

FRAME_SIZE = display.width * display.height * 2

try:
    # Создаем ОДИН постоянный буфер. При перезапуске скрипта 
    # MicroPython будет пытаться переиспользовать или перевыделить его чище.
    frame_buffer = bytearray(FRAME_SIZE)
    print("Буфер кадра успешно выделен в PSRAM")
except MemoryError:
    print("Критическая ошибка: Не удалось выделить память под буфер кадра!")
    # Если памяти совсем нет, пробуем аварийную очистку
    gc.collect()
    frame_buffer = bytearray(FRAME_SIZE)

def play_raw_video(filename, fps=24):
    # Размер одного кадра на экране: 320 * 172 * 2 байта = 110080 байт
    frame_size = display.width * display.height * 2
    
    # Создаем буфер кадра. Такой размер автоматически выделится в PSRAM
    gc.collect()
    frame_buffer = bytearray(frame_size)
    
    # Целевое время на один кадр в миллисекундах (для 24 fps это ~41 мс)
    frame_delay = int(1000 / fps)
    
    try:
        print(f"Открытие видео {filename}...")
        with open(filename, "rb") as f:
            while True:
                start_time = time.ticks_ms()
                
                # Читаем ровно один кадр из файла напрямую в буфер в PSRAM
                bytes_read = f.readinto(frame_buffer)
                
                # Если файл закончился (прочитано меньше, чем размер кадра) — выходим
                if bytes_read < frame_size:
                    print("Конец видеофайла")
                    break
                
                # Мгновенно выкидываем весь кадр на дисплей
                display.blit_buffer(frame_buffer, 0, 0, display.width, display.height)
                
                # Считаем, сколько заняло чтение с SD + вывод на экран
                elapsed = time.ticks_diff(time.ticks_ms(), start_time)
                
                # Удерживаем FPS. Если сработали быстрее 41 мс — спим остаток времени
                sleep_time = frame_delay - elapsed
                if sleep_time > 0:
                    time.sleep_ms(sleep_time)
                    
    except Exception as e:
        print(f"Ошибка воспроизведения: {e}")

# ==================== ОСНОВНОЙ ЦИКЛ ====================
time.sleep(2)

while True:
    # Запускаем видео по кругу
    play_raw_video("/sd/logo_ec.raw", fps=60)
    time.sleep(1) # Пауза перед повтором

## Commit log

2026-10-07 add testing ESP32S3
2026-10-07 for esp32s3

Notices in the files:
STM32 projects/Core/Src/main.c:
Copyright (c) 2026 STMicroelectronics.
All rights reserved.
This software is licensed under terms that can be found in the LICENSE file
